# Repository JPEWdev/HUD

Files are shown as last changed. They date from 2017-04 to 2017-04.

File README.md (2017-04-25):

# HUD
A vehicular Heads Up Display based on an Atmel

## Dependencies
This software depends uses avr-gcc and avr-libc to compile. To flash the sofware onto the device, you will need avrdude installed and an ISP programmer. You may need to tweak the make file if you use a programmer other than the AVRISP MkII.

## Compiling
To compile the software, simply run `make`

## Installing
To install the software onto the device, run `make writeflash`.

If you have a fresh part that has never been programmed before, you will need to program the fuse bits before you can program the main software. To do this, run `make writefuses`. This command is clocked at a low speed to ensure that it will work when the AVR is running off of either its internal oscialltor or the external crystal. This is fine, because the command is only writing the fuse bits, which doesn't take long

## Assembly
The HUD.brd file in the respository can be used to fabricate the main board. You can order all of the parts except for the ELM329 chip from [Digikey](www.digikey.com) using the [BOM.txt](./misc/BOM.txt) file (you can directly import this on the [DigiKey website](https://www.digikey.com/classic/ordering/addpart.aspx), use the "Upload to Cart" option). You can order the ELM329 from [ELM's website](https://www.elmelectronics.com/ic/elm329/)

Total cost for PCB fabrication and all components should be less than $200 USD.

## Display
The display that should be connected to the main board is the Noritake GU140X16G-7003 Vacuum Fluorescent Display. You will need to solder the jumper on the back to put the display into Synchronus Serial Mode (Short jumper J2 on the back of the display). Pins 1-6 on the 6 pin header should be wired to pins 1-6 on the display header of the main board in the same order (i.e. pin 1 to pin 1). Pin 1 on the display board header is the closest to the bottom of the board. Pin 7 on the main board is not used with the VFD display.

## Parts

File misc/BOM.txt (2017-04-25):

Qty	Value	Device	Package	Part	Description	Digikey PN	Link
1	680uF	1000UF-25V(PTH)	CPOL-RADIAL-1000UF-25V	C13	CAP-08070	493-1744-ND	https://www.digikey.com/short/3w5218
8	0.1uF	560PF-50V-5%(0603)	0603-CAP	C4,C7,C8,C11,C12,C14,C15,C16	CAP-08749	490-1532-1-ND	http://www.digikey.com/short/3f834t
2	13pF	560PF-50V-5%(0603)	0603-CAP	C9,C10	CAP-08749	490-1406-1-ND	http://www.digikey.com/short/3ft1m7
2	27pf	560PF-50V-5%(0603)	0603-CAP	C1,C2	CAP-08749	399-7888-1-ND	http://www.digikey.com/short/3ft149
2	560pF	560PF-50V-5%(0603)	0603-CAP	C3,C6	CAP-08749	1276-1278-1-ND	http://www.digikey.com/short/3ft14w
1	ATMEGA644A	ATMEGA644A	TQFP44	IC1	8-bit Microcontroller with 64K Bytes In-System Programmable Flash	ATMEGA644PA-AU-ND	http://www.digikey.com/short/3ft1m9
1	AVR_SPI	AVR_SPI_PRG_6PTH	2X3	J1	AVR ISP 6 Pin	SAM1114-03-ND	http://www.digikey.com/short/3ft1mw
1	100uF	CAP_POLPTH1	CPOL-RADIAL-100UF-25V	C5	Capacitor Polarized	493-1548-ND	http://www.digikey.com/short/3ft140
1	16 MHz	CRYSTAL-GROUNDED3.2X2.5	CRYSTAL-SMD-3.2X2.5	X1		SER4069CT-ND	http://www.digikey.com/short/3f83m1
1	4MHz	CRYSTALHC49US	HC49US	Y3	Various standard crystals. Proven footprints.	XC1735-ND	http://www.digikey.com/short/3f83hc
1	ODB-2	DB9MALE	DB9_MALE	JP3	DB9 Connector	A32091-ND	http://www.digikey.com/short/3ft1md
1	24V	DIODE-TVS16V	SOD-123	D9	Zener Diode	641-1660-1-ND	https://www.digikey.com/short/3w52dc
2	7V	DIODE-TVS16V	SOD-123	D10,D11	Zener Diode	F7470CT-ND	https://www.digikey.com/short/3w58rp
1	ELM329SOP	ELM329SOP	SO28W	U$4			https://www.elmelectronics.com/ic/elm329/
1	150uH	INDUCTORPWR	CDRH125	L1	Inductors	308-1938-1-ND	http://www.digikey.com/short/3f3b4h
8	GREEN	LED-GREENLARGE	LED-1206	D2,D3,D4,D5,D6,D7,D8,D12	Various green LEDs	404-1046-1-ND	http://www.digikey.com/short/3ft1m4
1	LM2576	LM2576S	TO263-5	IC2	Texas Instruments LM2576 Simple Switcher	LM2576SX-5.0/NOPBCT-ND	http://www.digikey.com/short/3ft1mr
1		M02LOCK	1X02_LOCK	JP4	Standard 2-pin 0.1" header. Use with		
1	BUTTONS	M05LOCK	1X05_LOCK	JP1	Header 5		
1	DISPLAY	M07LOCK	1X07_LOCK	JP5	Header 7		
1	MCP2561SOP	MCP2561SOP	SO08	U$2		MCP2561-E/SN-ND	http://www.digikey.com/short/3f83mn
1		NPNSOT323	SOT323	T1	NPN TRANSISTOR	MMST3904-FDICT-ND	https://www.digikey.com/short/3w58f5
2	100	RESISTOR0603-RES	0603-RES	R7,R8	Resistor	311-100HRCT-ND	https://www.digikey.com/short/3w9t3m
8	470	RESISTOR0603-RES	0603-RES	R1,R2,R3,R4,R5,R6,R11,R16	Resistor	311-470HRCT-ND	https://www.digikey.com/short/3w9t34
2	10K	RESISTOR0603-RES	0603-RES	R10,R13	Resistor	311-10KGRCT-ND	https://www.digikey.com/short/3w9t3d
1	127K	RESISTOR0603-RES	0603-RES	R12	Resistor	311-127KHRCT-ND	https://www.digikey.com/short/3w9tqj
1	20K	RESISTOR0603-RES	0603-RES	R14,R15	Resistor	311-20KGRCT-ND	https://www.digikey.com/short/3w9tqt
1	47K	RESISTOR0603-RES	0603-RES	R9	Resistor	311-47KGRCT-ND	https://www.digikey.com/short/3w9tqc
1	1N5822	SCHOTTKY-DIODEDO201T15	DO201T15	D1	Schottky Diode	1N5822-TPMSCT-ND	http://www.digikey.com/short/3ft1mq
2	SWITCH-MOMENTARY-2SMD-4	SWITCH-MOMENTARY-2SMD-4	TACTILE_SWITCH_TALL	S2,S4	Various NO switches- pushbuttons, reed, etc	CKN9112CT-ND	http://www.digikey.com/short/3f83mf
1		SWITCH-SPDTPTH	SWITCH-SPDT	S1	SPDT Switch	360-2133-ND	http://www.digikey.com/short/3f83mh
1	TPS27082LDDCRDDC6-M	TPS27082LDDCRDDC6-M	DDC6-M	U$1		296-35595-1-ND	http://www.digikey.com/short/3f83m2
1	DISPLAY	GU140X16G-7003			VFD Display	286-1035-ND	https://www.digikey.com/short/3n3hrh

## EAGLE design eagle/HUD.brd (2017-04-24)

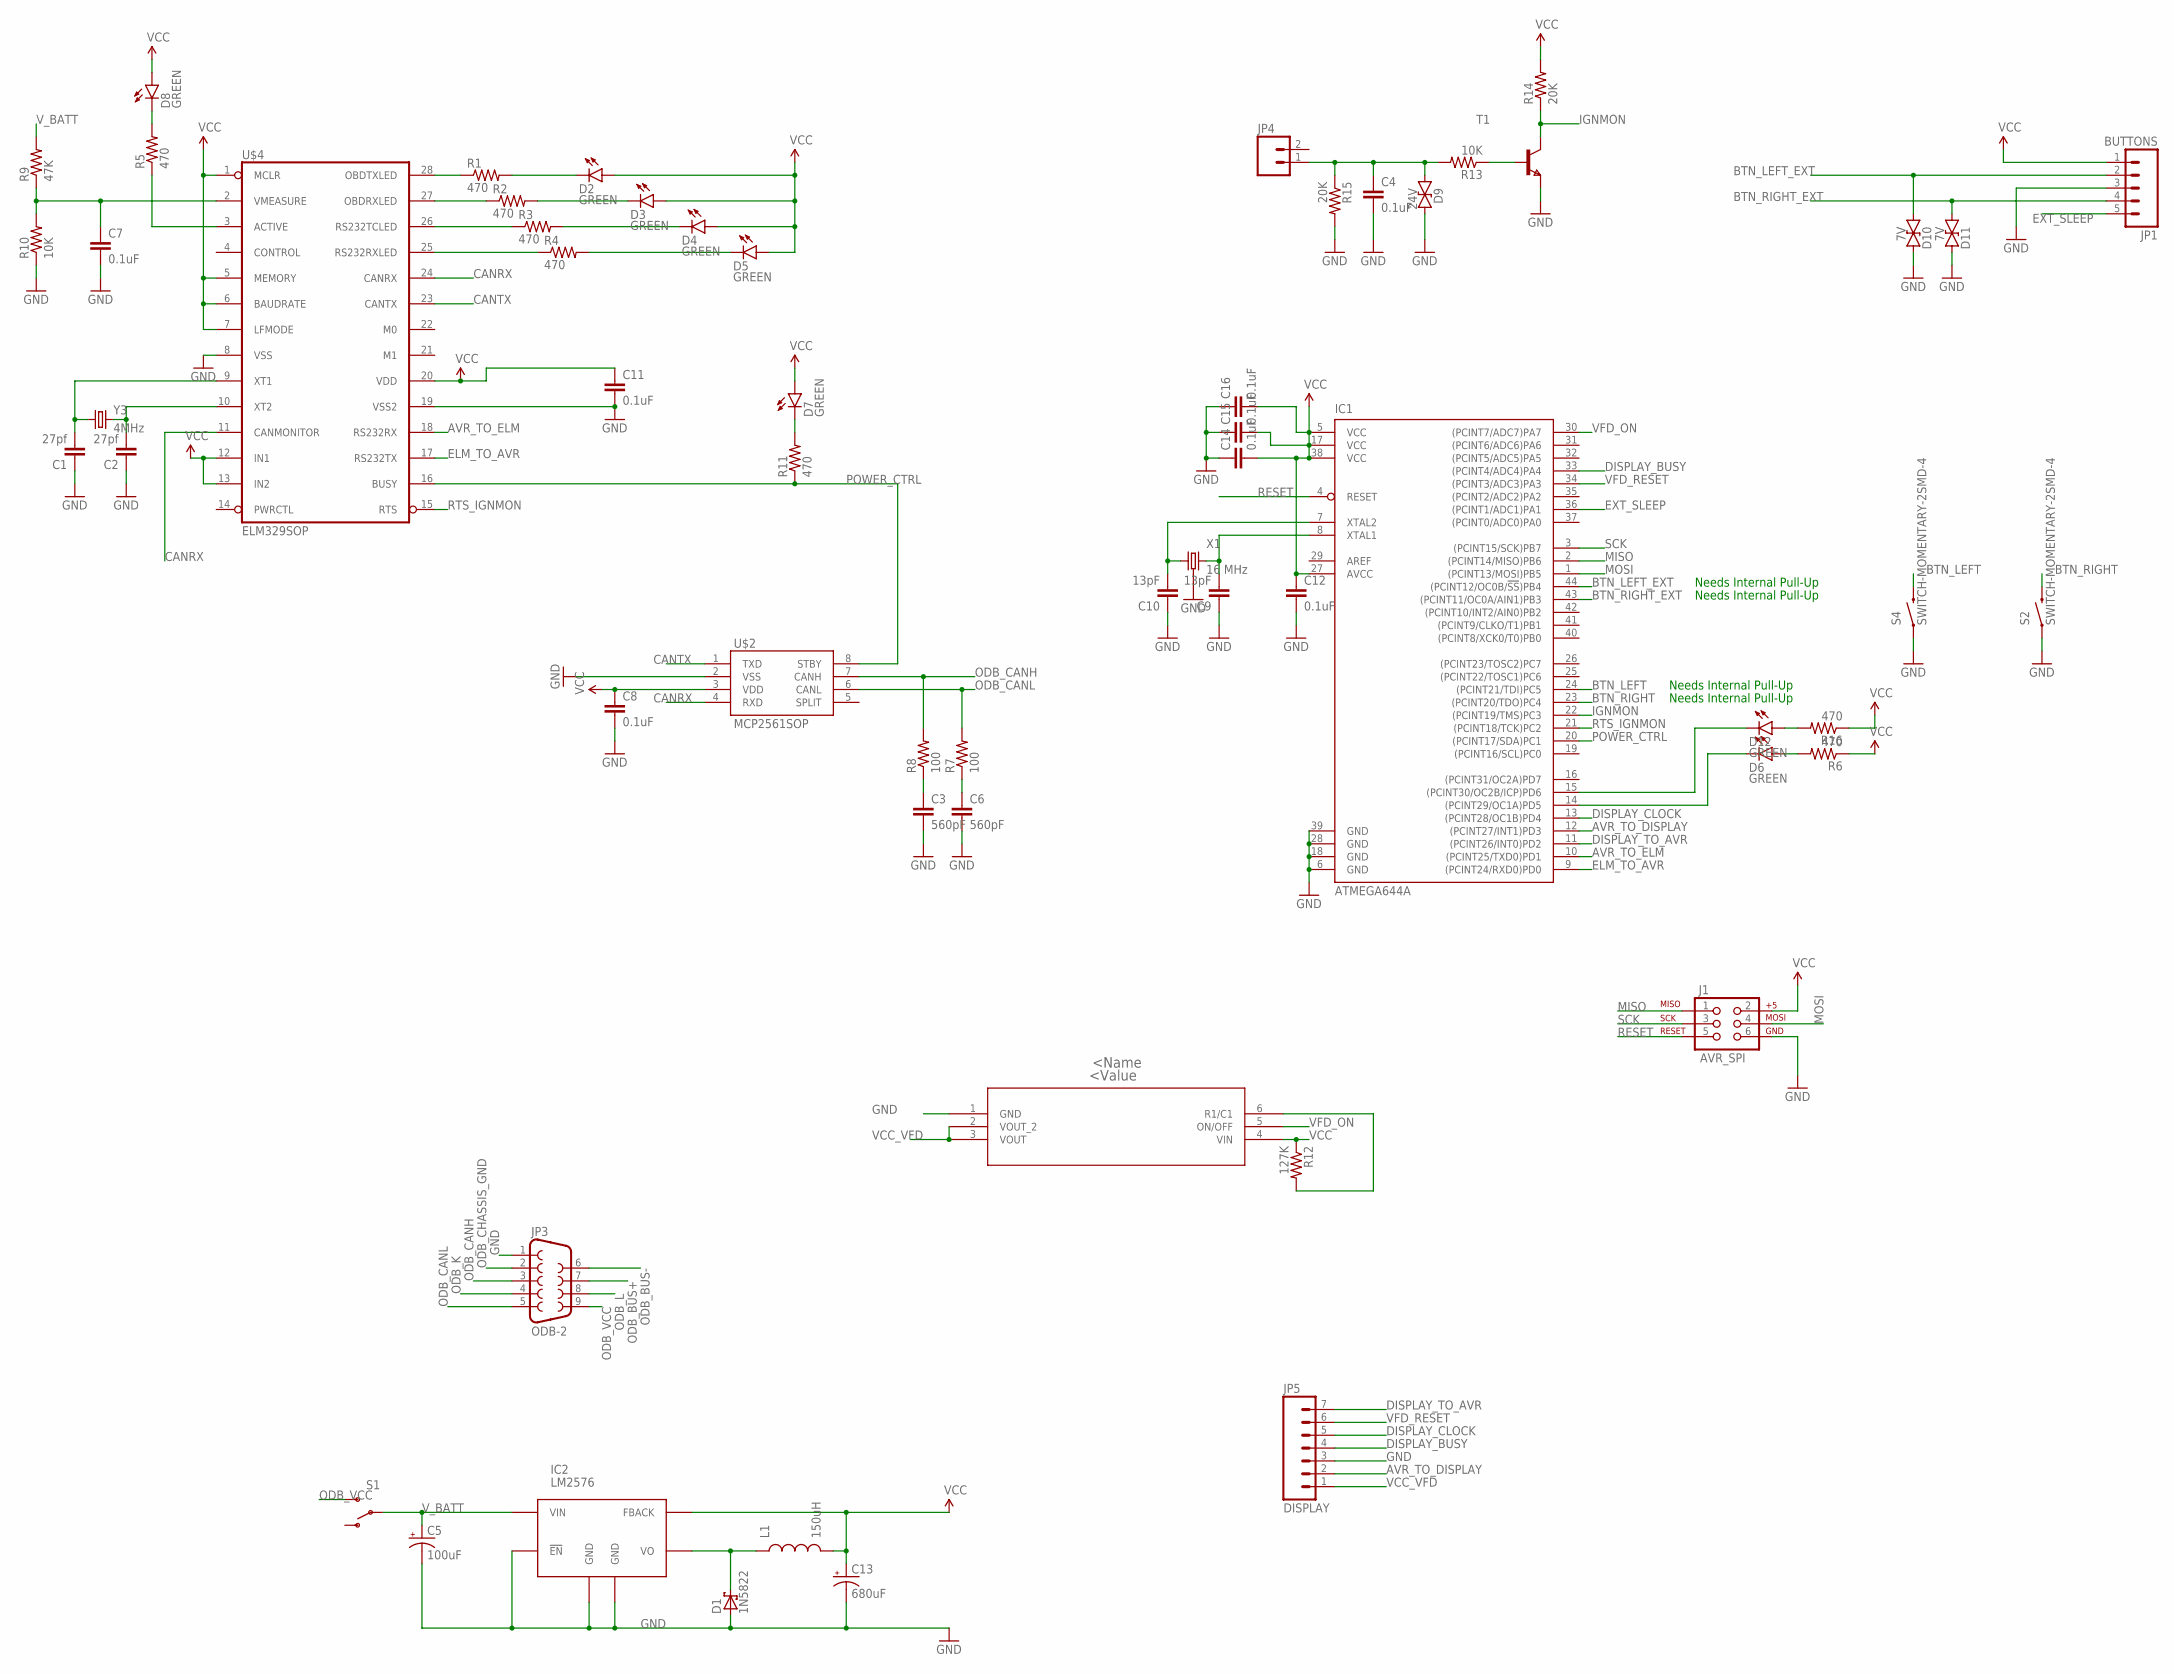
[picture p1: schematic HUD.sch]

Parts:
C1, C2: 27pf; 0603-CAP
C3, C6: 560pF; 0603-CAP
C4, C7, C8, C11, C12, C14, C15, C16: 0.1uF; 0603-CAP
C5: 100uF; CPOL-RADIAL-100UF-25V
C9, C10: 13pF; 0603-CAP
C13: 680uF; CPOL-RADIAL-1000UF-25V
D1: 1N5822; DO201T15
D2, D3, D4, D5, D6, D7, D8, D12: GREEN; LED-1206
D9: 24V; SOD-123
D10, D11: 7V; SOD-123
IC1: ATMEGA644A; TQFP44
IC2: LM2576; TO263-5
J1: AVR_SPI; 2X3
JP1: BUTTONS; 1X05_LOCK
JP3: ODB-2; DB9_MALE
JP4: M02LOCK; 1X02_LOCK
JP5: DISPLAY; 1X07_LOCK
L1: 150uH; CDRH125
R1, R2, R3, R4, R5, R6, R11, R16: 470; 0603-RES
R7, R8: 100; 0603-RES
R9: 47K; 0603-RES
R10, R13: 10K; 0603-RES
R12: 127K; 0603-RES
R14, R15: 20K; 0603-RES
S1: SWITCH-SPDTPTH; SWITCH-SPDT
S2, S4: SWITCH-MOMENTARY-2SMD-4; TACTILE_SWITCH_TALL
T1: NPNSOT323; SOT323
U$1: TPS27082LDDCRDDC6-M; DDC6-M
U$2: MCP2561SOP; SO08
U$4: ELM329SOP; SO28W
X1: 16 MHz; CRYSTAL-SMD-3.2X2.5
Y3: 4MHz; HC49US

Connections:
AVR_TO_DISPLAY: IC1.12 ((PCINT27/INT1)PD3), JP5.2
AVR_TO_ELM: IC1.10 ((PCINT25/TXD0)PD1), U$4.18 (RS232RX)
BTN_LEFT: IC1.24 ((PCINT21/TDI)PC5), S4.B2 (2)
BTN_LEFT_EXT: D10.A, IC1.44 ((PCINT12/OC0B/!SS!)PB4), JP1.2
BTN_RIGHT: IC1.23 ((PCINT20/TDO)PC4), S2.B2 (2)
BTN_RIGHT_EXT: D11.A, IC1.43 ((PCINT11/OC0A/AIN1)PB3), JP1.4
CANRX: U$2.4 (RXD), U$4.11 (CANMONITOR), U$4.24 (CANRX)
CANTX: U$2.1 (TXD), U$4.23 (CANTX)
DISPLAY_BUSY: IC1.33 ((PCINT4/ADC4)PA4), JP5.4
DISPLAY_CLOCK: IC1.13 ((PCINT28/OC1B)PD4), JP5.5
DISPLAY_TO_AVR: IC1.11 ((PCINT26/INT0)PD2), JP5.7
ELM_TO_AVR: IC1.9 ((PCINT24/RXD0)PD0), U$4.17 (RS232TX)
EXT_SLEEP: IC1.36 ((PCINT1/ADC1)PA1), JP1.5
GND: C1.1, C2.1, C3.2, C4.2, C5.2 (-), C6.2, C7.2, C8.2, C9.1, C10.1, C11.2, C12.2, C13.-, C14.1, C15.1, C16.1, D1.A, D9.C, D10.C, D11.C, IC1.6 (GND), IC1.18 (GND), IC1.28 (GND), IC1.39 (GND), IC2.3 (GND), IC2.5 (!EN), IC2.TAB (GND), J1.6, JP1.3, JP3.1, JP5.3, R10.1, R15.2, S2.A2 (1), S4.A2 (1), T1.3 (E), U$1.1 (GND), U$2.2 (VSS), U$4.8 (VSS), U$4.19 (VSS2), X1.2 (3), X1.4 (3)
IGNMON: IC1.22 ((PCINT19/TMS)PC3), R14.1, T1.1 (C)
MISO: IC1.2 ((PCINT14/MISO)PB6), J1.1
MOSI: IC1.1 ((PCINT13/MOSI)PB5), J1.4
unnamed: R12.2, U$1.6 (R1/C1)
unnamed: D7.C, R11.2
unnamed: C4.1, D9.A, JP4.1, R13.2, R15.1
unnamed: D6.C, IC1.14 ((PCINT29/OC1A)PD5)
unnamed: R13.1, T1.2 (B)
unnamed: D1.C, IC2.2 (VO), L1.1
unnamed: R1.1, U$4.28 (OBDTXLED)
unnamed: D12.A, R16.2
unnamed: R2.1, U$4.27 (OBDRXLED)
unnamed: D12.C, IC1.15 ((PCINT30/OC2B/ICP)PD6)
unnamed: R3.1, U$4.26 (RS232TCLED)
unnamed: R4.1, U$4.25 (RS232RXLED)
unnamed: C1.2, U$4.9 (XT1), Y3.1
unnamed: C2.2, U$4.10 (XT2), Y3.2
unnamed: R5.1, U$4.3 (ACTIVE)
unnamed: D2.C, R1.2
unnamed: D3.C, R2.2
unnamed: D4.C, R3.2
unnamed: D5.C, R4.2
unnamed: D8.C, R5.2
unnamed: D6.A, R6.2
unnamed: C3.1, R8.1
unnamed: C6.1, R7.1
unnamed: C7.1, R9.1, R10.2, U$4.2 (VMEASURE)
unnamed: C10.2, IC1.7 (XTAL2), X1.3 (1)
unnamed: C9.2, IC1.8 (XTAL1), X1.1 (2)
ODB_BUS+: JP3.7
ODB_BUS-: JP3.6
ODB_CANH: JP3.3, R8.2, U$2.7 (CANH)
ODB_CANL: JP3.5, R7.2, U$2.6 (CANL)
ODB_CHASSIS_GND: JP3.2
ODB_K: JP3.4
ODB_L: JP3.8
ODB_VCC: JP3.9, S1.3 (S)
POWER_CTRL: IC1.20 ((PCINT17/SDA)PC1), R11.1, U$2.8 (STBY), U$4.16 (BUSY)
RESET: IC1.4 (RESET), J1.5
RTS_IGNMON: IC1.21 ((PCINT18/TCK)PC2), U$4.15 (RTS)
SCK: IC1.3 ((PCINT15/SCK)PB7), J1.3
VCC: C8.1, C11.1, C12.1, C13.+, C14.2, C15.2, C16.2, D2.A, D3.A, D4.A, D5.A, D7.A, D8.A, IC1.5 (VCC), IC1.17 (VCC), IC1.27 (AVCC), IC1.38 (VCC), IC2.4 (FBACK), J1.2, JP1.1, L1.2, R6.1, R12.1, R14.2, R16.1, U$1.4 (VIN), U$2.3 (VDD), U$4.1 (MCLR), U$4.5 (MEMORY), U$4.6 (BAUDRATE), U$4.7 (LFMODE), U$4.12 (IN1), U$4.13 (IN2), U$4.20 (VDD)
VCC_VFD: JP5.1, U$1.2 (VOUT_2), U$1.3 (VOUT)
VFD_ON: IC1.30 ((PCINT7/ADC7)PA7), U$1.5 (ON/OFF)
VFD_RESET: IC1.34 ((PCINT3/ADC3)PA3), JP5.6
V_BATT: C5.1 (+), IC2.1 (VIN), R9.2, S1.2

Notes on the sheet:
Needs Internal Pull-Up

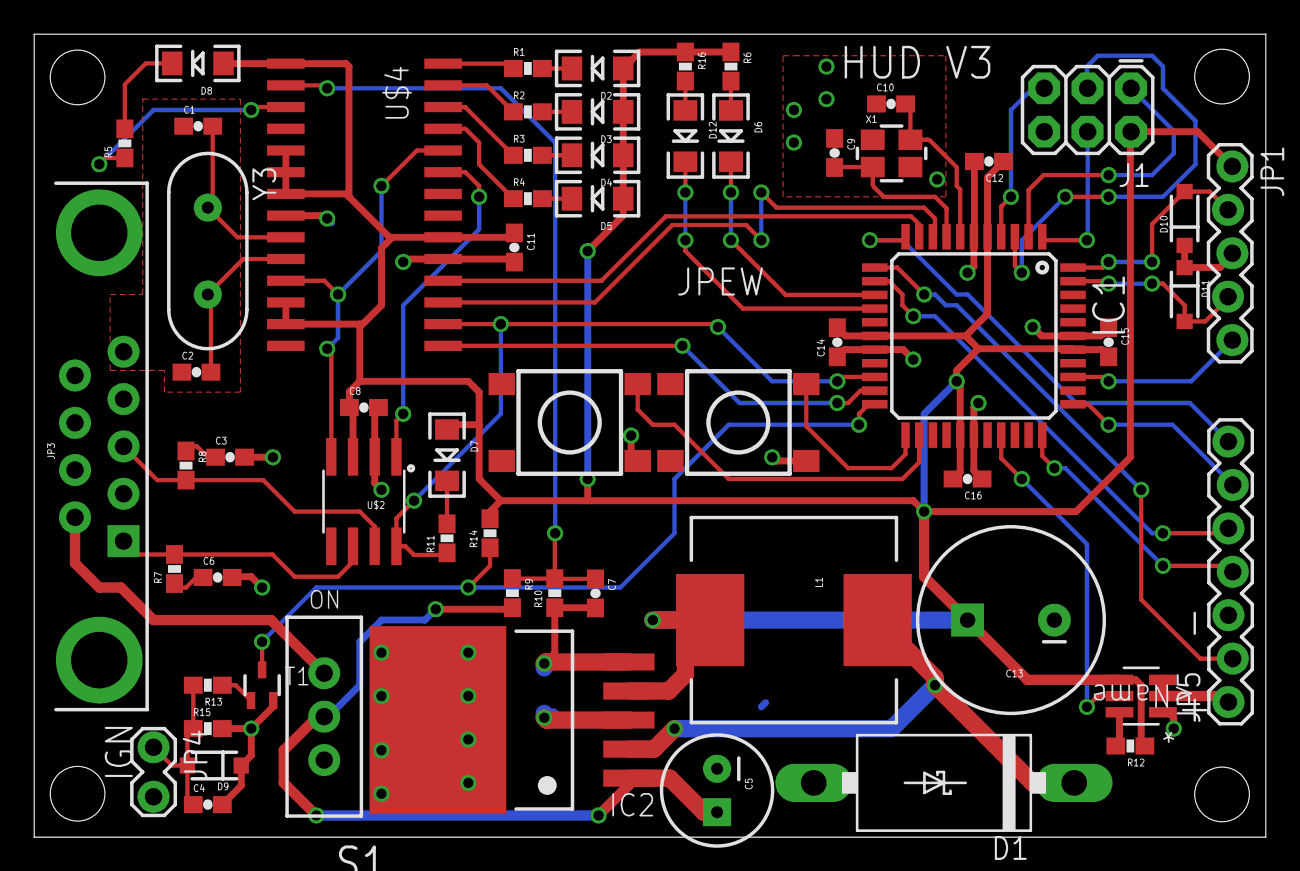
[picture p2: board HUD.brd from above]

Board: 2 copper layers, 72.1 x 47.0 mm, 61 parts (0 on the bottom side), 55 nets.

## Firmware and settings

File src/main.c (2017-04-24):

/*
 * Copyright 2017 Joshua Watt
 *
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
 * THE SOFTWARE IS PROVIDED "AS IS", WITHOUT WARRANTY OF ANY KIND, EXPRESS OR
 * IMPLIED, INCLUDING BUT NOT LIMITED TO THE WARRANTIES OF MERCHANTABILITY,
 * FITNESS FOR A PARTICULAR PURPOSE AND NONINFRINGEMENT. IN NO EVENT SHALL THE
 * AUTHORS OR COPYRIGHT HOLDERS BE LIABLE FOR ANY CLAIM, DAMAGES OR OTHER
 * LIABILITY, WHETHER IN AN ACTION OF CONTRACT, TORT OR OTHERWISE, ARISING
 * FROM, OUT OF OR IN CONNECTION WITH THE SOFTWARE OR THE USE OR OTHER DEALINGS
 * IN THE SOFTWARE.
 */
#include <stdlib.h>
#include <avr/eeprom.h>
#include <avr/interrupt.h>
#include <avr/io.h>
#include <avr/sleep.h>
#include <limits.h>
#include <stdio.h>
#include <string.h>

#include "btn.h"
#include "diagnostics.h"
#include "elm327.h"
#include "hud_data.h"
#include "layout.h"
#include "led.h"
#include "menu.h"
#include "obd_data.h"
#include "timer.h"
#include "uart.h"
#include "utl.h"
#include "vfd.h"

#define ROW0_Y      (0)
#define ROW1_Y      (VFD_LINE_HGHT / 2)
#define MAX_PAGES   (4)

#define SEARCH_X    (VFD_WDTH - VFD_CHAR_WDTH)
#define SEARCH_Y    (ROW0_Y)

#define CONN_X      (VFD_WDTH - VFD_CHAR_WDTH)
#define CONN_Y      (ROW1_Y)

#define DISPLAY_UART UART1
#define IGNMON_PIN PIN_C3
#define POWER_CTL_PIN PIN_C1
#define EXT_SLEEP PIN_A1

#define MAX_IDLE_TIME (10000)

#ifndef NO_VFD
    #define display_ready() VFD_ready()
#else
    #define display_ready() ( UART_tx_level( DISPLAY_UART ) == 0 )
#endif

enum layout_idx {
    LAYOUT_2,
    LAYOUT_3L,
    LAYOUT_3R,
    LAYOUT_4,
    LAYOUT_CNT,
};

struct watch_state_type {
    bool updated;
    bool valid;
    char text_buffer[ HUD_DATA_LEN ];
};

struct data_page_type {
    enum layout_idx layout;
    hud_data_t8 data[DATA_CNT];
};

static struct data_page_type EEMEM watch_pages_eemem[MAX_PAGES] = {
    {
        LAYOUT_3L,
        {
        HUD_DATA_SPEED_MPH,
        HUD_DATA_RPM,
        HUD_DATA_INST_ECON,
        }
    },
    {
        LAYOUT_4,
        {
        HUD_DATA_AVG_ECON,
        HUD_DATA_FUEL_LVL,
        HUD_DATA_BARO_PRES_MMHG,
        HUD_DATA_AIR_TEMP_F,
        }
    },
};

static const struct screen_layout_type *const layouts[] = {
    &layout_2_LR,
    &layout_3L,
    &layout_3R,
    &layout_4
};

STATIC_ASSERT(cnt_of_array(layouts) == LAYOUT_CNT);

static uint8_t EEMEM num_pages_eemem = 2;

static uint8_t EEMEM brightness_eemem = VFD_BRIGHT_DEFAULT;

static struct data_page_type watch_pages[MAX_PAGES];

static const char splash_str[] = "Hello Joshua";
static const char invalid_data_str[] = "---";

static struct data_page_type const *my_cur_page = NULL;
static uint8_t my_cur_page_idx = 0;
static uint8_t my_num_pages;
static bool my_searching = false;
static bool my_connected = true;
static uint8_t my_last_updt = 0;
static struct watch_state_type my_state[DATA_CNT];

static void
show_dtcs(bool wait)
{
    ELM327_dtc_type *dtcs;
    uint8_t dtc_cnt;
    uint8_t i;

    dtc_cnt = ELM327_get_dtc(&dtcs);

    VFD_clear();
    VFD_char_width(VFD_CHAR_WDTH_PROP_1);

    if (dtc_cnt > 0) {
        for (i = 0; i < dtc_cnt; i++) {
            VFD_clear();
            VFD_set_cursor(0, 0);
            VFD_printf("DTC %u of %u", (int)(i + 1), (int)dtc_cnt);
            VFD_set_cursor(0, 1);
            VFD_printf("%s", dtcs[i].code);

            /* Wait 30 seconds for a button press */
            BTN_wait(wait ? 0 : 30000);
        }
    } else {
        VFD_set_cursor(0, 0);
        VFD_printf("No DTCs");
        BTN_wait(wait ? 0 : 1000);
    }

    free(dtcs);
}

static enum menu_id
clear_dtc_menu(enum menu_id id, void *param)
{
    enum menu_id m;

    VFD_soft_reset();
    m = menu_yes_no("Are you sure?");

    if (m == MENU_YES) {
        VFD_char_width(VFD_CHAR_WDTH_PROP_1);
        VFD_printf("Clearing DTCs");
        ELM327_clear_dtcs();
        timer_sleep(1000);
    }

    return (m == MENU_TIMEOUT) ? m : MENU_NONE;
}

static enum menu_id
view_dtc_menu(enum menu_id id, void *param)
{
    VFD_soft_reset();
    show_dtcs(true);
    return MENU_NONE;
}

static void
choose_data_items(struct data_page_type *dp)
{
    struct menu_type data_menu_items[DATA_CNT];
    struct menu_type hud_menu[HUD_DATA_CNT];
    enum menu_id m;
    int i;
    uint8_t data_idx;

    // Construct HUD menu
    for (i = 0; i < HUD_DATA_CNT; i++) {
        hud_menu[i].id = i;
        hud_menu[i].string = HUD_data_name(i);
        hud_menu[i].proc = NULL;
    }

    for (i = 0; i < DATA_CNT; i++) {
        if (dp->data[i] >= HUD_DATA_CNT)
            dp->data[i] = HUD_DATA_NONE;
    }

    while (true) {
        for (i = 0; i < layouts[dp->layout]->wndw_cnt; i++) {
            data_menu_items[i].id = i;
            data_menu_items[i].string = HUD_data_name(dp->data[i]);
            data_menu_items[i].proc = NULL;
        }

        m = menu_process(layouts[dp->layout], data_menu_items,
                layouts[dp->layout]->wndw_cnt, 0, &dp);

        if (m == MENU_BACK || m == MENU_TIMEOUT)
            break;

        if (m < layouts[dp->layout]->wndw_cnt) {
            data_idx = m;

            m = menu_process(&layout_4, hud_menu, cnt_of_array(hud_menu),
                    dp->data[data_idx], NULL);

            if (m == MENU_TIMEOUT)
                break;

            if ((int)m < HUD_DATA_CNT)
                dp->data[data_idx] = m;
        }
    }
}

static enum menu_id
page_menu(enum menu_id id, void *param)
{
    struct menu_type layout_menu[ LAYOUT_CNT ];
    enum menu_id m;
    uint8_t idx = id;
    struct data_page_type dp;
    int i;

    // Copy data page settings
    dp = watch_pages[idx];

    // Choose layout
    for (i = 0; i < LAYOUT_CNT; i++) {
        layout_menu[i].id = i;
        layout_menu[i].string = layouts[i]->name;
        layout_menu[i].proc = NULL;
    }

    m = menu_process(layouts[LAYOUT_4], layout_menu, cnt_of_array(layout_menu),
            dp.layout, NULL);

    if (m < cnt_of_array(layout_menu)) {
        dp.layout = m;

        choose_data_items(&dp);

        // Save new settings
        watch_pages[idx] = dp;
        eeprom_write_block(&dp, &watch_pages_eemem[idx], sizeof(dp));
    }

    return (m == MENU_TIMEOUT) ? m : MENU_NONE;
}

static enum menu_id
layout_configure_menu(enum menu_id id, void *param)
{
    static struct menu_type page_menu_items[MAX_PAGES + 1];
    static char page_names[MAX_PAGES][10];
    uint8_t i;
    enum menu_id m;

    for (i = 0; i < my_num_pages; i++) {
        page_menu_items[i].id = i;
        page_menu_items[i].string = page_names[i];
        sprintf(page_names[i], "Page %u", i + 1);
        page_menu_items[i].proc = page_menu;
    }
    page_menu_items[i].id = MENU_BACK;
    page_menu_items[i].string = "Done";
    page_menu_items[i].proc = NULL;

    m = menu_process(&layout_4, page_menu_items, my_num_pages + 1,
            my_cur_page_idx, NULL);

    return (m == MENU_TIMEOUT) ? m : MENU_NONE;
}

static enum menu_id
brightness_menu(enum menu_id id, void *param)
{
    static const struct menu_type menu[] = {
    {   VFD_BRIGHT_12_5,    "12.5%",    NULL    },
    {   VFD_BRIGHT_25,      "25%",      NULL    },
    {   VFD_BRIGHT_37_5,    "37.5%",    NULL    },
    {   VFD_BRIGHT_50,      "50%",      NULL    },
    {   VFD_BRIGHT_62_5,    "62.5%",    NULL    },
    {   VFD_BRIGHT_75,      "75%",      NULL    },
    {   VFD_BRIGHT_87_5,    "87.5%",    NULL    },
    {   VFD_BRIGHT_100,     "100%",     NULL    },
    };

    enum menu_id m;
    uint8_t i;
    VFD_bright_lvl_t8 lvl;

    for (i = 0; i < cnt_of_array(menu); i++) {
        if (menu[i].id == VFD_brightness_get())
            break;
    }

    m = menu_process(&layout_4, menu, cnt_of_array(menu), i, NULL);

    if (m < MENU_RESERVED) {
        lvl = (VFD_bright_lvl_t8)m;

        VFD_brightness_set(lvl);
        eeprom_update_byte(&brightness_eemem, lvl);
    }

    return (m == MENU_TIMEOUT) ? m : MENU_NONE;
}

static enum menu_id
num_pages_menu(enum menu_id id, void *param)
{
    static struct menu_type menu[MAX_PAGES];
    static char menu_names[MAX_PAGES][10];

    uint8_t i;
    enum menu_id m;

    for (i = 0; i < MAX_PAGES; i++) {
        menu[i].id = i;
        menu[i].string = menu_names[i];
        menu[i].proc = NULL;

        sprintf(menu_names[i], "%u Pages", i + 1);
    }

    m = menu_process(&layout_4, menu, cnt_of_array(menu), my_num_pages - 1, NULL);

    if (m < MAX_PAGES) {
        my_num_pages = m + 1;

        eeprom_update_byte( &num_pages_eemem, my_num_pages );

        if (my_cur_page_idx >= my_num_pages)
            my_cur_page_idx = 0;
    }

    return (m == MENU_TIMEOUT) ? m : MENU_NONE;
}

static enum menu_id
fuel_econ_menu(enum menu_id id, void *param)
{
    static const struct menu_type options[] = {
        {   false,  "Only when shown",  NULL    },
        {   true,   "Always",           NULL    },
    };

    enum menu_id m;

    m = menu_process(&layout_2_TB, options, cnt_of_array(options),
            HUD_get_fuel_econ_always_on(), NULL);

    if (m == true || m == false) {
        HUD_set_fuel_econ_always_on(!!m);
    }

    return (m == MENU_TIMEOUT) ? m : MENU_NONE;
}

static enum menu_id
settings_menu(enum menu_id id, void *param)
{
    static const struct menu_type menu[] = {
        {   MENU_NONE,  "Fuel Econ",    fuel_econ_menu      },
        {   MENU_BACK,  "Back",         NULL                },
    };

    enum menu_id m;

    m = menu_process(&layout_4, menu, cnt_of_array(menu), 0, NULL);

    return (m == MENU_TIMEOUT) ? m : MENU_NONE;
}

static const struct menu_type main_menu[] = {
    {   MENU_NONE,  "Num Pages",    num_pages_menu          },
    {   MENU_NONE,  "Page Layout",  layout_configure_menu   },
    {   MENU_NONE,  "Settings",     settings_menu           },
    {   MENU_NONE,  "Brightness",   brightness_menu         },
    {   MENU_NONE,  "View DTCs",    view_dtc_menu           },
    {   MENU_NONE,  "Clear DTCs",   clear_dtc_menu          },
    {   MENU_NONE,  "Diagnostics",  diagnostics_menu        },

    {   MENU_BACK,  "Back",         NULL                    },
};

static void
dec_idx(void)
{
    if (my_cur_page_idx == 0)
        my_cur_page_idx = my_num_pages - 1;
    else
        my_cur_page_idx--;
}

static void
inc_idx(void)
{
    my_cur_page_idx = (my_cur_page_idx + 1) % my_num_pages;
}

static void
destroy_layout(void)
{
    uint8_t i;

    /*
     * Remove existing data items
     */
    if (my_cur_page) {
        for (i = 0; i < layouts[my_cur_page->layout]->wndw_cnt; i++) {
            HUD_data_remove(my_cur_page->data[i]);
            VFD_delete_window(layouts[my_cur_page->layout]->windows[i].window);
        }

        my_cur_page = NULL;
    }
}

static void
create_layout(struct data_page_type const *page)
{
    uint8_t i;

    if (my_cur_page != page) {
        my_cur_page = page;

        for (i = 0; i < layouts[my_cur_page->layout]->wndw_cnt; i++) {
            /*
             * Register for HUD Data
             */
            my_state[i].updated = true;
            my_state[i].valid = true;
            strcpy(my_state[i].text_buffer, invalid_data_str);
            HUD_data_add(my_cur_page->data[i]);
        }

        create_layout_windows(layouts[my_cur_page->layout]);
    }
}

static void
change_layout(void)
{
    struct data_page_type const *page = &watch_pages[my_cur_page_idx];
    uint8_t btns;

    do {
        destroy_layout();
        create_layout(page);

        VFD_win_select(VFD_WIN_BASE);
        VFD_clear();
        VFD_char_width(VFD_CHAR_WDTH_PROP_1);
        VFD_font_size(2, 2);
        VFD_printf("Page %u", my_cur_page_idx + 1);
        VFD_char_width(VFD_CHAR_WDTH_DEFAULT);

        btns = BTN_wait(1000);

        if (btns & BTN_L_PRESS)
            dec_idx();
        else if (btns & BTN_R_PRESS)
            inc_idx();
    } while (btns != 0);
}

static void
low_power_mode(void)
{
    struct pin_change_handler ignmon_int_handler;
    struct pin_change_handler power_ctl_int_handler;
    uint8_t btn;

    VFD_soft_reset();
    VFD_char_width(VFD_CHAR_WDTH_PROP_1);
    VFD_printf("Powering Down...");

    ELM327_low_power_mode();

    btn = BTN_wait(3000);

    VFD_power_down();

    if (btn)
        return;

    LED_off(LED_STATUS);
    LED_off(LED_POWER);
    pin_set_output(EXT_SLEEP, PIN_LOW);

    /*
     * Register a pin change interrupt for the ignition and power control pins.
     * We don't need the handler to actually do anything, just wake us up from
     * sleep mode
     */
    ignmon_int_handler.pin = IGNMON_PIN;
    ignmon_int_handler.callback = NULL;
    ignmon_int_handler.param = NULL;
    pin_enable_interrupt(&ignmon_int_handler);

    power_ctl_int_handler.pin = POWER_CTL_PIN;
    power_ctl_int_handler.callback = NULL;
    power_ctl_int_handler.param = NULL;
    pin_enable_interrupt(&power_ctl_int_handler);

    set_sleep_mode(SLEEP_MODE_PWR_DOWN);

    /*
     * Disable interrupts to ensure atomic checking of pin
     */
    cli();
    while(true) {
        LED_on(LED_STATUS);
        if (!pin_read(IGNMON_PIN) || !pin_read(POWER_CTL_PIN) || BTN_check())
            break;
        LED_off(LED_STATUS);

        sleep_enable();

        /*
         * The instruction immediately after SEI is guaranteed to before any
         * interrupts are handled, ensuring the device is asleep before the
         * interrupt that could wake it up would occur
         */
        sei();
        sleep_cpu();

        sleep_disable();
        cli();
    }
    sei();

    pin_disable_interrupt(&ignmon_int_handler);
    pin_disable_interrupt(&power_ctl_int_handler);

    pin_set_output(EXT_SLEEP, PIN_HIGH);

    LED_on(LED_POWER);
}

static void
process_display(void)
{
    uint8_t i;
    uint8_t cur = 0;

    if (my_searching != ELM327_searching()) {
        VFD_win_select(VFD_WIN_BASE);
        my_searching = ELM327_searching();
        VFD_font_size(1, 1);
        VFD_set_cursor(SEARCH_X, SEARCH_Y);
        VFD_write_string(my_searching ? "S" : " ");
    } else if (my_connected != ELM327_connected()) {
#ifndef NO_VFD
        VFD_win_select(VFD_WIN_BASE);
        my_connected = ELM327_connected();
        VFD_font_size(1, 1);
        VFD_set_cursor(CONN_X, CONN_Y);
        VFD_write_string(my_connected ? " " : "X");
#else
        UART_printf(DISPLAY_UART, "Not Connected\n\r");
#endif
    } else {
        for (i = 1; i < layouts[my_cur_page->layout]->wndw_cnt; i++) {
            cur = (my_last_updt + i) % DATA_CNT;
            if (my_state[cur].updated) {
                my_state[cur].updated = false;
#ifndef NO_VFD
                VFD_win_select(layouts[my_cur_page->layout]->windows[cur].window);
                VFD_clear();
                VFD_set_cursor(0, 0);
                /*--------------------------------------------------------
                    * VFD_set_cursor( watch_data[cur].x, watch_data[cur].y );
                    *------------------------------------------------------*/
                VFD_font_size(layouts[my_cur_page->layout]->windows[cur].font_sz,
                        layouts[my_cur_page->layout]->windows[cur].font_sz);
                VFD_write_string(my_state[ cur ].text_buffer);
#endif
                break;
            }
        }
#ifdef NO_VFD
        if (i != layouts[my_cur_page->layout]->wndw_cnt) {
            // The display was updated. Draw it again
            for (i = 0; i < layouts[my_cur_page->layout]->wndw_cnt; i++)
                UART_printf(DISPLAY_UART, "%u: %s\n\r", i, my_state[i].text_buffer);
        }
#endif

        my_last_updt = cur;
    }
}

static void
process_hud_data(void)
{
    uint8_t i;
    char temp_buffer[HUD_DATA_LEN];

    /*
     * Check if there are any changes in the HUD data module. If any data has
     * changed, update it and mark it as changed
     */
    for (i = 0; i < layouts[my_cur_page->layout]->wndw_cnt; i++) {
        if (HUD_data_updated(my_cur_page->data[i])
                && HUD_data_get(my_cur_page->data[i], temp_buffer)) {

            if (strcmp(temp_buffer, my_state[i].text_buffer) != 0) {
                my_state[i].updated = true;
                strcpy(my_state[i].text_buffer, temp_buffer);
            }
        } else if (!HUD_data_valid(my_cur_page->data[i]) && my_state[i].valid) {
            strcpy(my_state[i].text_buffer, invalid_data_str);
            my_state[i].updated = true;
            my_state[i].valid = false;
        }
    }
}

static bool
process_buttons(void)
{
    uint8_t btns = BTN_process();

    if (btns & BTN_L_PRESS) {
        dec_idx();
        change_layout();
        return true;
    }

    if (btns & BTN_R_PRESS) {
        inc_idx();
        change_layout();
        return true;
    }

    if (btns & BTN_R_HOLD) {
        destroy_layout();

        // Process menu
        menu_process(&layout_4, main_menu, cnt_of_array(main_menu), 0, NULL);

        // Re-create layout
        VFD_soft_reset();
        change_layout();
        return true;
    }

    if (btns & BTN_L_HOLD) {
        destroy_layout();

        choose_data_items(&watch_pages[my_cur_page_idx]);

        eeprom_write_block(&watch_pages[my_cur_page_idx],
                &watch_pages_eemem[my_cur_page_idx],
                sizeof(watch_pages[my_cur_page_idx]));

        // Re-create layout
        VFD_soft_reset();
        change_layout();
        return true;
    }

    return false;
}

static void
main_loop(void)
{
    uint32_t last_btn_time;

    VFD_connect();
    ELM327_connect();

    while(true) {
        #ifndef NO_VFD
            VFD_init();
            VFD_brightness_set(eeprom_read_byte(&brightness_eemem));
            VFD_char_width(VFD_CHAR_WDTH_PROP_1);

            VFD_write_string(splash_str);
            timer_sleep(5000);
        #else
            UART_init(DISPLAY_UART, UART_TX | UART_RX, 38400);

            UART_printf(DISPLAY_UART, "Hello... ");
            timer_sleep(5000);
            UART_printf(DISPLAY_UART, "ready\n\r");
        #endif

        LED_strobe(LED_STATUS, 1000);

        ELM327_init();
        ELM327_set_linefeed(false);

        LED_strobe(LED_STATUS, 10);

        #ifndef NO_VFD
            VFD_clear();
            VFD_set_cursor(0, 0);
            VFD_printf("%s (%X)", ELM327_get_proto_str(), (unsigned)ELM327_get_proto());
            timer_sleep(1000);
        #else
            UART_printf(DISPLAY_UART, "Protocol %u\n\r", proto);
        #endif

        show_dtcs(false);

        HUD_data_init();

        my_connected = true;
        my_searching = false;
        my_last_updt = 0;

        LED_strobe(LED_STATUS, 500);

        change_layout();

        last_btn_time = timer_get();

        while(true) {
            if (timer_get() - last_btn_time > MAX_IDLE_TIME
                    && pin_read(IGNMON_PIN)) {
                /*
                 * Debounce
                 */
                timer_sleep(1000);
                if (pin_read(IGNMON_PIN))
                    break;
            }

            timer_process();
            HUD_process();

            if (process_buttons())
                last_btn_time = timer_get();

            process_hud_data();

            if (display_ready())
                process_display();
        }

    /*
     * Enter low power mode
     */
    destroy_layout();
    low_power_mode();
    }
}

void
bypass_loop(void)
{
    uint8_t out;
    uint8_t in;
    while (true) {
        out = 0;
        in = PIND;
        if (in & _BV(2))
            out |= _BV(1);
        if (in & _BV(0))
            out |= _BV(3);
        PORTD = out;
    }
}

int
main(int argc, char **argv)
{
    uint8_t btns;

    timer_init();
    LED_init();
    BTN_init();

    pin_set_direction(IGNMON_PIN, PIN_INPUT);
    //pin_set_pullup(IGNMON_PIN, true);

    pin_set_direction(POWER_CTL_PIN, PIN_INPUT);

    pin_set_direction(EXT_SLEEP, PIN_OUTPUT);
    pin_set_output(EXT_SLEEP, PIN_HIGH);

    LED_on(LED_POWER);
    LED_strobe(LED_STATUS, 250);

    eeprom_read_block(watch_pages, watch_pages_eemem, sizeof(watch_pages));
    my_num_pages = eeprom_read_byte(&num_pages_eemem);

    sei();
    /*
     * Wait for external devices to settle down
     */
    timer_sleep( 1000 );

    btns = BTN_process();

    if (btns & BTN_L_HOLD) {
        LED_on(LED_STATUS);
        pin_set_direction(PIN_D1, PIN_OUTPUT);
        pin_set_direction(PIN_D0, PIN_INPUT);

        pin_set_direction(PIN_D3, PIN_OUTPUT);
        pin_set_direction(PIN_D2, PIN_INPUT);

        /*
         * RTS
         */
        pin_set_direction(PIN_C2, PIN_OUTPUT);
        pin_set_output(PIN_C2, PIN_HIGH);

        /*
         * Display Power
         */
        pin_set_direction(PIN_A7, PIN_OUTPUT);
        pin_set_output(PIN_A7, PIN_HIGH);

        bypass_loop();
    } else {
        main_loop();
    }

    return 0;
}

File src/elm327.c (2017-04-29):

/*
 * Copyright 2017 Joshua Watt
 *
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
 * THE SOFTWARE IS PROVIDED "AS IS", WITHOUT WARRANTY OF ANY KIND, EXPRESS OR
 * IMPLIED, INCLUDING BUT NOT LIMITED TO THE WARRANTIES OF MERCHANTABILITY,
 * FITNESS FOR A PARTICULAR PURPOSE AND NONINFRINGEMENT. IN NO EVENT SHALL THE
 * AUTHORS OR COPYRIGHT HOLDERS BE LIABLE FOR ANY CLAIM, DAMAGES OR OTHER
 * LIABILITY, WHETHER IN AN ACTION OF CONTRACT, TORT OR OTHERWISE, ARISING
 * FROM, OUT OF OR IN CONNECTION WITH THE SOFTWARE OR THE USE OR OTHER DEALINGS
 * IN THE SOFTWARE.
 */
#include <ctype.h>
#include <stdio.h>
#include <stdlib.h>
#include <string.h>

#include "elm327.h"
#include "led.h"
#include "obd_pid.h"
#include "pin.h"
#include "timer.h"
#include "uart.h"
#include "utl.h"

#define IS_WHITESPACE(_c) (((_c) == ' ') || ((_c) == '\t'))

#define UART (UART0)
#define INIT_BAUD (38400)
#define BAUD (500000)
#define ELM_CLOCK_FREQ (4000000)

#define write_data(_data, _sz ) UART_tx(UART, _data, _sz)
#define printf( ... ) UART_printf(UART1, __VA_ARGS__)
#define ENDL "\n\r"

#ifndef DEBUG
    #ifdef printf
        #undef printf
    #endif

    #define printf(...)
#endif

#define LINE_BUFFER_SZ  (50)

#define TIMEOUT (10000)

#define RTS_PIN PIN_C2
#define POWER_CTRL_PIN PIN_C1

#define proto_is_ISO_15765(_p)    \
    (((_p) == ELM327_PROTO_ISO_15765_4_CAN_11_500_KBAUD) ||    \
     ((_p) == ELM327_PROTO_ISO_15765_4_CAN_29_500_KBAUD) ||    \
     ((_p) == ELM327_PROTO_ISO_15765_4_CAN_11_250_KBAUD) ||    \
     ((_p) == ELM327_PROTO_ISO_15765_4_CAN_29_250_KBAUD))

static const char endl[] = ENDL;

static const char *const dtc_prefix[] = {
    /* 0    */  "P0",
    /* 1    */  "P1",
    /* 2    */  "P2",
    /* 3    */  "P3",
    /* 4    */  "C0",
    /* 5    */  "C1",
    /* 6    */  "C2",
    /* 7    */  "C3",
    /* 8    */  "B0",
    /* 9    */  "B1",
    /* A    */  "B2",
    /* B    */  "B3",
    /* C    */  "U0",
    /* D    */  "U1",
    /* E    */  "U2",
    /* F    */  "U3"
    };

static bool s_searching;
static bool s_cannot_connect;
static ELM327_proto_type s_cur_proto;
static char s_cur_proto_str[50];
static bool s_auto_proto;

static bool s_elm_ready;

static uint8_t last_pid;

static ELM327_data_clbk my_data_clbk;
static ELM327_no_data_clbk my_no_data_clbk;
static bool my_echo_enabled;

static void
reset_state(void)
{
    s_searching = false;
    s_cannot_connect = false;
    s_cur_proto = ELM327_PROTO_AUTO;
    s_cur_proto_str[0] = '\0';
    s_auto_proto = true;
    last_pid = 0;
    my_echo_enabled = true;
    s_elm_ready = false;
}

static uint8_t
read_data(uint8_t *buffer, uint8_t size)
{
    uint8_t cur = 0;

    /*
     * Read one byte at a time. We have to do this to skip the occasional
     * NUL byte the ELM can insert into the output stream (listed errata)
     */
    while (cur < size) {
        if (UART_rx_nb(UART, &buffer[cur], 1) == 0)
            break;

        /*
         * If this byte isn't a NUL, advance the buffer
         */
        if (buffer[cur])
            cur++;
    }
    return cur;
}

static char const *
get_data(void)
{
    static char s_rspns_buffer[LINE_BUFFER_SZ + 1];
    static char s_line_buffer[LINE_BUFFER_SZ + 1];
    static uint8_t s_line_buffer_cur = 0;
    static uint8_t s_line_buffer_sz = 0;

    bool process;
    uint8_t read_sz;

    process = false;

    read_sz = read_data((void *)&s_line_buffer[s_line_buffer_sz],
            LINE_BUFFER_SZ - s_line_buffer_sz);

    s_line_buffer_sz += read_sz;

    if (s_line_buffer_cur < s_line_buffer_sz) {
        switch (s_line_buffer[s_line_buffer_cur]) {
        case '\n':
        case '\r':
            if (s_line_buffer_cur + 1 < s_line_buffer_sz) {
                /*
                 * Copy data to response buffer and NULL terminate
                 */
                memcpy(s_rspns_buffer, s_line_buffer, s_line_buffer_cur);
                s_rspns_buffer[s_line_buffer_cur] = '\0';

                /*
                 * Move remaining data to the beginning of the buffer
                 */
                s_line_buffer_cur++;
                memmove(s_line_buffer, &s_line_buffer[s_line_buffer_cur],
                        s_line_buffer_sz - s_line_buffer_cur);
                s_line_buffer_sz -= s_line_buffer_cur;
                s_line_buffer_cur = 0;

                process = true;
                printf("got newline" ENDL);
            }
            break;

        case '>':
            s_line_buffer_sz--;
            memmove(&s_line_buffer[s_line_buffer_cur],
                    &s_line_buffer[s_line_buffer_cur + 1], s_line_buffer_sz);
            s_elm_ready = true;
            printf("ELM327 Ready" ENDL);
            break;

        default:
            s_line_buffer_cur++;
            break;
        }
    }

    return process ? s_rspns_buffer : NULL;
}

static void write_string(char const *str)
{
    write_data(str, strlen(str));
}

static bool
wait_for_string(char const *s, size_t len, uint32_t max_time)
{
    char const *data;
    uint32_t start_time = timer_get();

    while (true) {
        while ((data = get_data()) == NULL && timer_get() - start_time < max_time)
            ;

        if (data == NULL)
            return false;

        if (len > 0 && strncmp(data, s, len) == 0)
            return true;

        if (strcmp(data, s) == 0)
            return true;
    }
}

static uint8_t
parse_hex_string(char const *str, uint8_t *dest_buf, uint8_t dest_sz,
        char const **end )
{
    char c;
    uint8_t nibble;
    uint8_t val;
    uint8_t dest_pos;
    bool done;

    nibble = 1;
    dest_pos = 0;

    if (dest_sz == 0)
        return 0;

    memset(dest_buf, 0, dest_sz);

    c = *str;
    val = 0xFF;
    done = false;

    while (c && !done) {
        val = 0xFF;

        if (c >= '0' && c <= '9')
            val = c - '0';
        else if (c >= 'A' && c <= 'F')
            val = (c - 'A') + 10;
        else if (c >= 'a' && c <= 'f')
            val = (c - 'a') + 10;
        else if (!IS_WHITESPACE(c))
            break;

        if (val != 0xFF) {
            dest_buf[dest_pos] |= val << (nibble * 4);

            if (nibble == 0) {
                nibble = 1;
                dest_pos++;

                if (dest_pos >= dest_sz)
                    done = true;
            } else {
                nibble--;
            }
        }

        str++;
        c = *str;
    }

    if (val != 0xFF && dest_pos < dest_sz)
        dest_buf[dest_pos] |= val << (nibble * 4);

    if (end)
        *end = str;

    return dest_pos;
}

static void
wake_up(void)
{
    /*
     * Strobe the RTS pin. This will ensure that we get a prompt if the ELM is
     * busy doing something else, or wake it up from low power mode
     */
    pin_set_output(RTS_PIN, PIN_LOW);
    timer_sleep(100);
    pin_set_output(RTS_PIN, PIN_HIGH);
}

static void
wait_ready(void)
{
    if (!s_elm_ready) {
        printf("Waiting for ready\n\r");
        ELM327_process(true);
    }
}
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

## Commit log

2017-04-24 Initial code commit
    Add all the initial code and eagle files for the HUD
    [HUD.brd, HUD.sch]
2017-04-25 Add BOM
    Adds Bill of Materials
    [BOM.tsv]
2017-04-25 Rename BOM
    Renames the BOM file to be compatible with DigiKey's website
2017-04-29 Add diagnostic page for showing PID values
    Adds a page that shows the hex value for all available PIDs
2017-04-29 Remove PID size table
    Removes the PID size table from the ELM driver and instead passes the
    size along in the callback

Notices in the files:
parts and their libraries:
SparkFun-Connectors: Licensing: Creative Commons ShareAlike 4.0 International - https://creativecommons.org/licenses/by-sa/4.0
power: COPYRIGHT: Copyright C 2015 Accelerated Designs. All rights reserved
